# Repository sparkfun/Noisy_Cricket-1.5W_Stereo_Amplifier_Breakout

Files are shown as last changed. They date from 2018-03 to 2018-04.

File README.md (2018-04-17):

SparkFun Noisy Cricket Stereo Amplifier - 1.5W
==========================================

Noisy Cricket

[*SparkFun Noisy Cricket Stereo Amplifier - 1.5W (DEV-14475)*](https://www.sparkfun.com/products/14475)

The Noisy Cricket is a 300mW stereo amplifier which can be configured to output up to 1.5W of mono amplification.
With a dual-gang pot you can control the volume with a single pot, as well as turn power on and off!

Repository Contents
-------------------
* **/Hardware** - All Eagle design files (.brd, .sch)
* **/Production** - Test bed files and production panel files

Documentation
--------------
* **[Hookup Guide](https://learn.sparkfun.com/tutorials/noisy-cricket-stereo-amplifier---15w-hookup-guide)** - Basic hookup guide for the Noisy Cricket.

License Information
-------------------

This product is _**open source**_! 

Please review the LICENSE.md file for license information. 

If you have any questions or concerns on licensing, please contact techsupport@sparkfun.com.

Distributed as-is; no warranty is given.

- Your friends at SparkFun.

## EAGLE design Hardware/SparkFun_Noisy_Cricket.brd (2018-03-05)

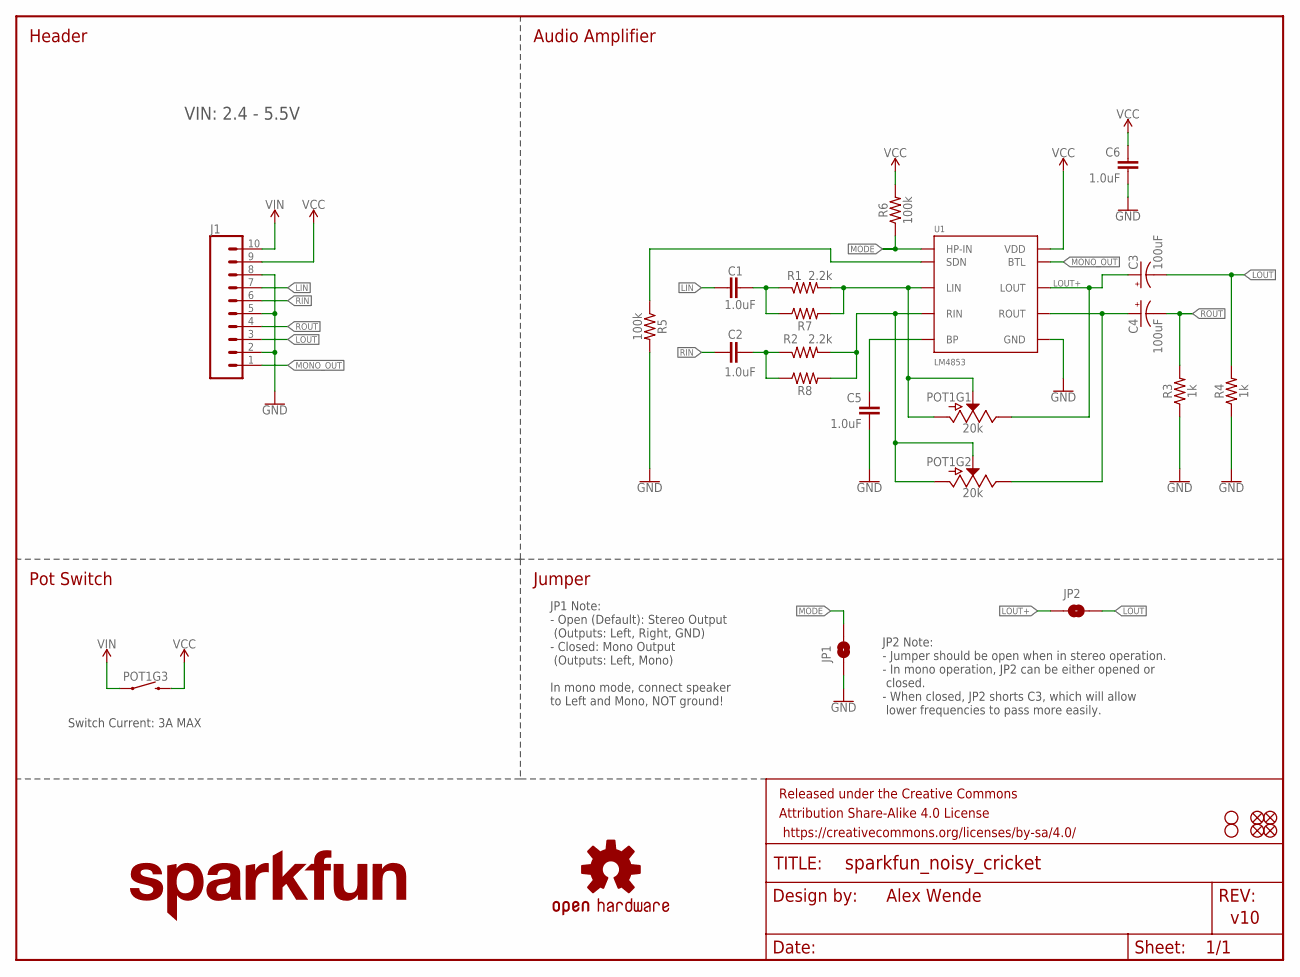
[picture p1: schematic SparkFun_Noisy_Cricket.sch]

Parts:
C1, C2, C5, C6: 1.0uF; 0603
C3, C4: 100uF; PANASONIC_D
FD1, FD2, FD3, FD4: FIDUCIALUFIDUCIAL; FIDUCIAL-MICRO
FRAME1: FRAME-LETTER; CREATIVE_COMMONS
H1, H2: STAND-OFF
J1: CONN_10NO_SILK_PTH_FEMALE; 1X10_NO_SILK
JP1, JP2: JUMPER-SMT_2_NO_NO-SILK; SMT-JUMPER_2_NO_NO-SILK
LOGO1: SFE_LOGO_NAME.1_INCH; SFE_LOGO_NAME_.1
LOGO2: OSHW-LOGOS; OSHW-LOGO-S
POT1: 20k; POT-DUAL-SWITCH-PTH
R1, R2: 2.2k; 0603
R3, R4: 1k; 0603
R5, R6: 100k; 0603
R7, R8: AXIAL-0.3-KIT
U1: LM4853; TFSOP-10

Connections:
5V: C6.1, J1.9, POT1.SW2 (2), R6.2, U1.VDD
GND: C5.2, C6.2, J1.2, J1.5, J1.8, JP1.1, R3.1, R4.1, R5.2, U1.GND
LIN: C1.1, J1.7
LOUT: C3.-, J1.3, JP2.2, R4.2
LOUT+: C3.+, JP2.1, POT1.A3 (E), U1.LOUT
MODE: JP1.2, R6.1, U1.HP-IN
MONO_OUT: J1.1, U1.BTL
unnamed: C1.2, R1.1, R7.P$1 (1)
unnamed: C5.1, U1.BP
unnamed: C2.2, R2.1, R8.P$1 (1)
unnamed: R5.1, U1.SDN
unnamed: C4.+, POT1.B3 (E), U1.ROUT
unnamed: POT1.A1 (A), POT1.A2 (S), R1.2, R7.P$2 (2), U1.LIN
unnamed: POT1.B1 (A), POT1.B2 (S), R2.2, R8.P$2 (2), U1.RIN
RIN: C2.1, J1.6
ROUT: C4.-, J1.4, R3.2
VIN: J1.10, POT1.SW1 (1)

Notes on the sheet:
JP1 Note: - Open (Default): Stereo Output (Outputs: Left, Right, GND) - Closed: Mono Output (Outputs: Left, Mono) In mono mode, connect speaker to Left and Mono, NOT ground!
Jumper
Audio Amplifier
Header
Pot Switch
Alex Wende
v10
VIN: 2.4 - 5.5V
Switch Current: 3A MAX
JP2 Note: - Jumper should be open when in stereo operation. - In mono operation, JP2 can be either opened or closed. - When closed, JP2 shorts C3, which will allow lower frequencies to pass more easily.

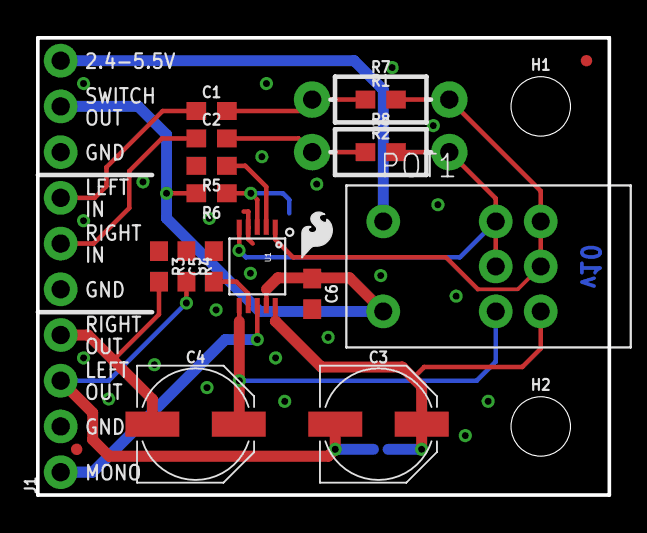
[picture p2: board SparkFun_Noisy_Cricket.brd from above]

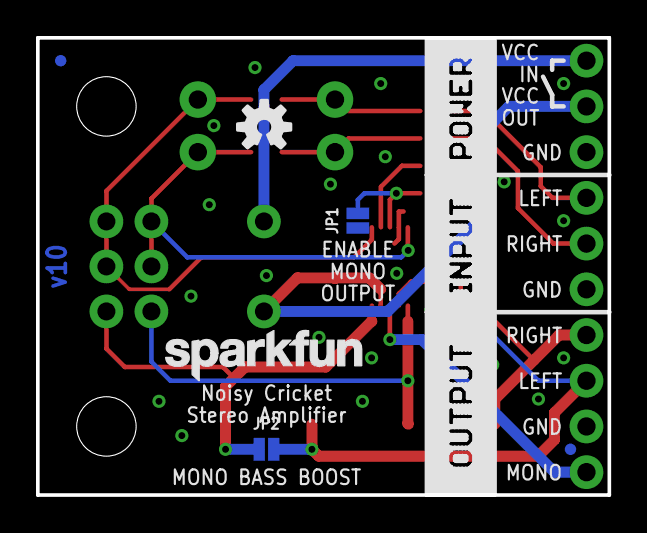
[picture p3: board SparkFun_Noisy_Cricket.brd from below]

Board: 2 copper layers, 31.8 x 25.4 mm, 29 parts (6 on the bottom side), 17 nets.

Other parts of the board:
U$1: SFE_LOGO_FLAME_.1

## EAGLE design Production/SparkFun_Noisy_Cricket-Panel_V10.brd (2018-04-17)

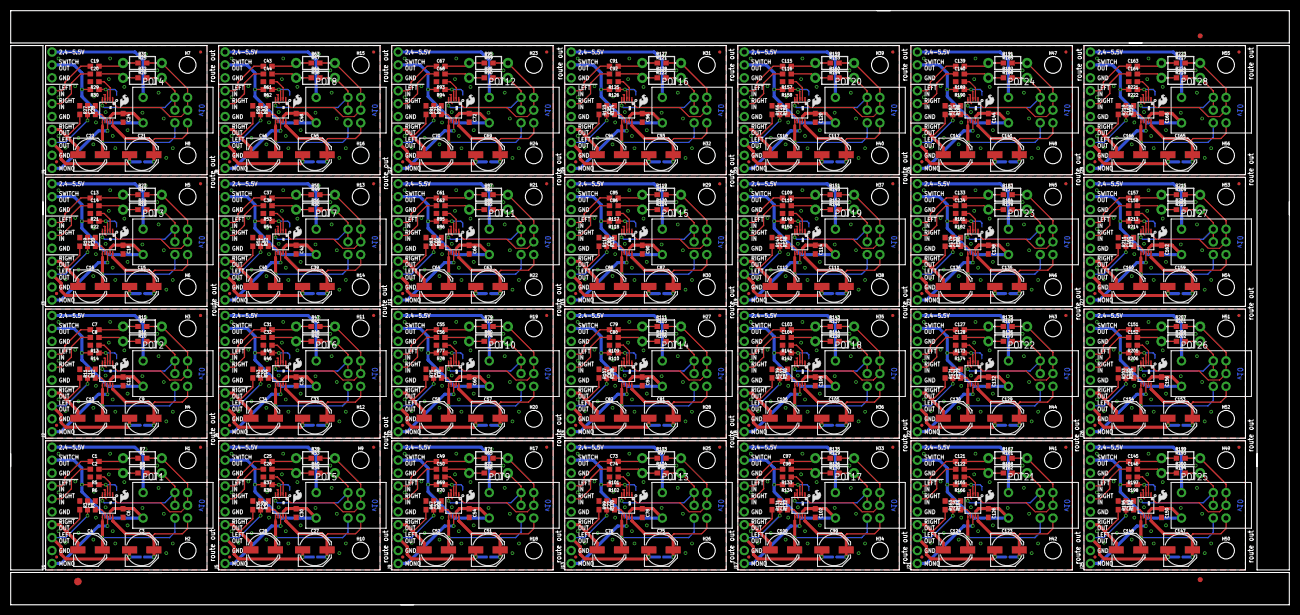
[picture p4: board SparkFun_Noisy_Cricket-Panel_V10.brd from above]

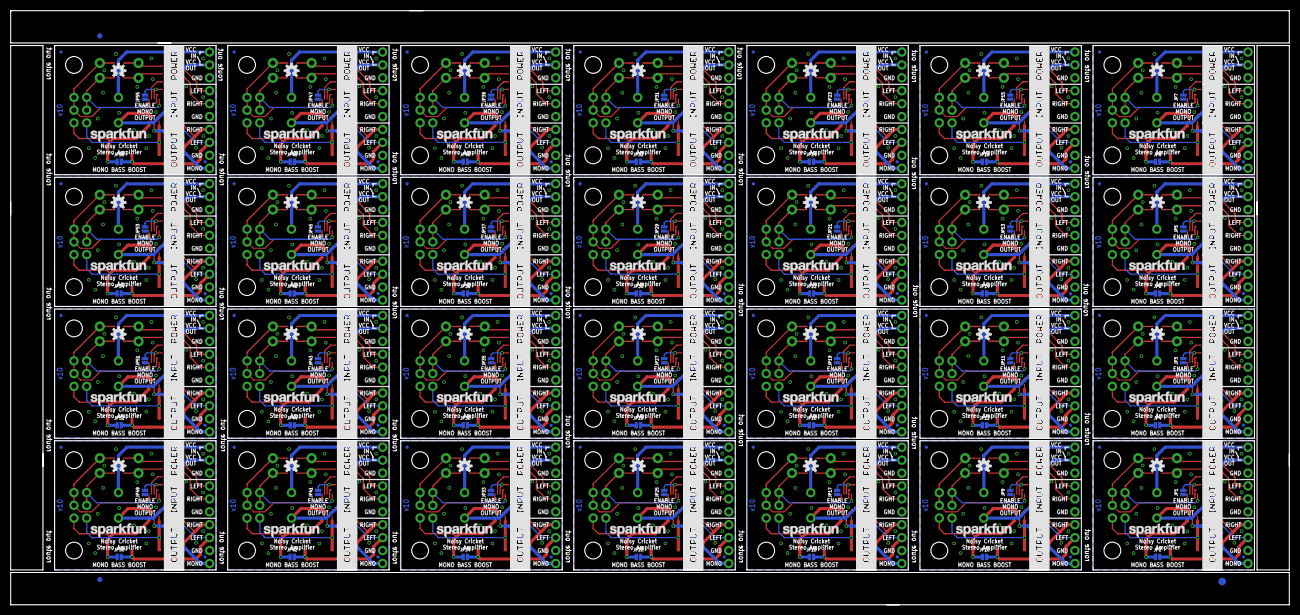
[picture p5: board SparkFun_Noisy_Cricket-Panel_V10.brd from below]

Board: 2 copper layers, 251.5 x 116.8 mm, 790 parts (171 on the bottom side), 476 nets.

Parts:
C1, C2, C5, C6, C7, C8, C11, C12, C13, C14, C17, C18, C19, C20, C23, C24, C25, C26, C29, C30, C31, C32, C35, C36, C37, C38, C41, C42, C43, C44, C47, C48, C49, C50, C53, C54, C55, C56, C59, C60, C61, C62, C65, C66, C67, C68, C71, C72, C73, C74, C77, C78, C79, C80, C83, C84, C85, C86, C89, C90, C91, C92, C95, C96, C97, C98, C101, C102, C103, C104, C107, C108, C109, C110, C113, C114, C115, C116, C119, C120, C121, C122, C125, C126, C127, C128, C131, C132, C133, C134, C137, C138, C139, C140, C143, C144, C145, C146, C149, C150, C151, C152, C155, C156, C157, C158, C161, C162, C163, C164, C167, C168: 1.0uF; 0603
C3, C4, C9, C10, C15, C16, C21, C22, C27, C28, C33, C34, C39, C40, C45, C46, C51, C52, C57, C58, C63, C64, C69, C70, C75, C76, C81, C82, C87, C88, C93, C94, C99, C100, C105, C106, C111, C112, C117, C118, C123, C124, C129, C130, C135, C136, C141, C142, C147, C148, C153, C154, C159, C160, C165, C166: 100uF; PANASONIC_D
E$1, E$2: FIDUCIAL-1.5X3
E$3, E$4, E$5, E$7: FIDUCIAL-1X2
FD1, FD2, FD3, FD4, FD5, FD6, FD7, FD8, FD9, FD10, FD11, FD12, FD13, FD14, FD15, FD16, FD17, FD18, FD19, FD20, FD21, FD22, FD23, FD24, FD25, FD26, FD27, FD28, FD29, FD30, FD31, FD32, FD33, FD34, FD35, FD36, FD37, FD38, FD39, FD40, FD41, FD42, FD43, FD44, FD45, FD46, FD47, FD48, FD49, FD50, FD51, FD52, FD53, FD54, FD55, FD56, FD57, FD58, FD59, FD60, FD61, FD62, FD63, FD64, FD65, FD66, FD67, FD68, FD69, FD70, FD71, FD72, FD73, FD74, FD75, FD76, FD77, FD78, FD79, FD80, FD81, FD82, FD83, FD84, FD85, FD86, FD87, FD88, FD89, FD90, FD91, FD92, FD93, FD94, FD95, FD96, FD97, FD98, FD99, FD100, FD101, FD102, FD103, FD104, FD105, FD106, FD107, FD108, FD109, FD110, FD111, FD112: FIDUCIALUFIDUCIAL; FIDUCIAL-MICRO
H1, H2, H3, H4, H5, H6, H7, H8, H9, H10, H11, H12, H13, H14, H15, H16, H17, H18, H19, H20, H21, H22, H23, H24, H25, H26, H27, H28, H29, H30, H31, H32, H33, H34, H35, H36, H37, H38, H39, H40, H41, H42, H43, H44, H45, H46, H47, H48, H49, H50, H51, H52, H53, H54, H55, H56: STAND-OFF
J1, J2, J3, J4, J5, J6, J7, J8, J9, J10, J11, J12, J13, J14, J15, J16, J17, J18, J19, J20, J21, J22, J23, J24, J25, J26, J27, J28: 1X10_NO_SILK
JP1, JP2, JP3, JP4, JP5, JP6, JP7, JP8, JP9, JP10, JP11, JP12, JP13, JP14, JP15, JP16, JP17, JP18, JP19, JP20, JP21, JP22, JP23, JP24, JP25, JP26, JP27, JP28, JP29, JP30, JP31, JP32, JP33, JP34, JP35, JP36, JP37, JP38, JP39, JP40, JP41, JP42, JP43, JP44, JP45, JP46, JP47, JP48, JP49, JP50, JP51, JP52, JP53, JP54, JP55, JP56: SMT-JUMPER_2_NO_NO-SILK
LOGO1, LOGO3, LOGO5, LOGO7, LOGO9, LOGO11, LOGO13, LOGO15, LOGO17, LOGO19, LOGO21, LOGO23, LOGO25, LOGO27, LOGO29, LOGO31, LOGO33, LOGO35, LOGO37, LOGO39, LOGO41, LOGO43, LOGO45, LOGO47, LOGO49, LOGO51, LOGO53, LOGO55: SFE_LOGO_NAME.1_INCH; SFE_LOGO_NAME_.1
LOGO2, LOGO4, LOGO6, LOGO8, LOGO10, LOGO12, LOGO14, LOGO16, LOGO18, LOGO20, LOGO22, LOGO24, LOGO26, LOGO28, LOGO30, LOGO32, LOGO34, LOGO36, LOGO38, LOGO40, LOGO42, LOGO44, LOGO46, LOGO48, LOGO50, LOGO52, LOGO54, LOGO56: OSHW-LOGOS; OSHW-LOGO-S
POT1, POT2, POT3, POT4, POT5, POT6, POT7, POT8, POT9, POT10, POT11, POT12, POT13, POT14, POT15, POT16, POT17, POT18, POT19, POT20, POT21, POT22, POT23, POT24, POT25, POT26, POT27, POT28: 20k; POT-DUAL-SWITCH-PTH
R1, R2, R9, R10, R17, R18, R25, R26, R33, R34, R41, R42, R49, R50, R57, R58, R65, R66, R73, R74, R81, R82, R89, R90, R97, R98, R105, R106, R113, R114, R121, R122, R129, R130, R137, R138, R145, R146, R153, R154, R161, R162, R169, R170, R177, R178, R185, R186, R193, R194, R201, R202, R209, R210, R217, R218: 2.2k; 0603
R3, R4, R11, R12, R19, R20, R27, R28, R35, R36, R43, R44, R51, R52, R59, R60, R67, R68, R75, R76, R83, R84, R91, R92, R99, R100, R107, R108, R115, R116, R123, R124, R131, R132, R139, R140, R147, R148, R155, R156, R163, R164, R171, R172, R179, R180, R187, R188, R195, R196, R203, R204, R211, R212, R219, R220: 1k; 0603
R5, R6, R13, R14, R21, R22, R29, R30, R37, R38, R45, R46, R53, R54, R61, R62, R69, R70, R77, R78, R85, R86, R93, R94, R101, R102, R109, R110, R117, R118, R125, R126, R133, R134, R141, R142, R149, R150, R157, R158, R165, R166, R173, R174, R181, R182, R189, R190, R197, R198, R205, R206, R213, R214, R221, R222: 100k; 0603
R7, R8, R15, R16, R23, R24, R31, R32, R39, R40, R47, R48, R55, R56, R63, R64, R71, R72, R79, R80, R87, R88, R95, R96, R103, R104, R111, R112, R119, R120, R127, R128, R135, R136, R143, R144, R151, R152, R159, R160, R167, R168, R175, R176, R183, R184, R191, R192, R199, R200, R207, R208, R215, R216, R223, R224: AXIAL-0.3-KIT
U1, U2, U3, U4, U5, U6, U7, U8, U9, U10, U11, U12, U13, U14, U15, U16, U17, U18, U19, U20, U21, U22, U23, U24, U25, U26, U27, U28: LM4853; TFSOP-10
U$1, U$2, U$3, U$4, U$5, U$6, U$7, U$8, U$9, U$10, U$11, U$12, U$13, U$14, U$15, U$16, U$17, U$18, U$19, U$20, U$21, U$22, U$23, U$24, U$25, U$26, U$27, U$28: SFE_LOGO_FLAME_.1

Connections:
5V: C6.1, J1.9, POT1.SW2, R6.2, U1.VDD
5V1: C12.1, J2.9, POT2.SW2, R14.2, U2.VDD
5V2: C18.1, J3.9, POT3.SW2, R22.2, U3.VDD
5V3: C24.1, J4.9, POT4.SW2, R30.2, U4.VDD
5V4: C30.1, J5.9, POT5.SW2, R38.2, U5.VDD
5V5: C36.1, J6.9, POT6.SW2, R46.2, U6.VDD
5V6: C42.1, J7.9, POT7.SW2, R54.2, U7.VDD
5V7: C48.1, J8.9, POT8.SW2, R62.2, U8.VDD
5V8: C54.1, J9.9, POT9.SW2, R70.2, U9.VDD
5V9: C60.1, J10.9, POT10.SW2, R78.2, U10.VDD
5V10: C66.1, J11.9, POT11.SW2, R86.2, U11.VDD
5V11: C72.1, J12.9, POT12.SW2, R94.2, U12.VDD
5V12: C78.1, J13.9, POT13.SW2, R102.2, U13.VDD
5V13: C84.1, J14.9, POT14.SW2, R110.2, U14.VDD
5V14: C90.1, J15.9, POT15.SW2, R118.2, U15.VDD
5V15: C96.1, J16.9, POT16.SW2, R126.2, U16.VDD
5V16: C102.1, J17.9, POT17.SW2, R134.2, U17.VDD
5V17: C108.1, J18.9, POT18.SW2, R142.2, U18.VDD
5V18: C114.1, J19.9, POT19.SW2, R150.2, U19.VDD
5V19: C120.1, J20.9, POT20.SW2, R158.2, U20.VDD
5V20: C126.1, J21.9, POT21.SW2, R166.2, U21.VDD
5V21: C132.1, J22.9, POT22.SW2, R174.2, U22.VDD
5V22: C138.1, J23.9, POT23.SW2, R182.2, U23.VDD
5V23: C144.1, J24.9, POT24.SW2, R190.2, U24.VDD
5V24: C150.1, J25.9, POT25.SW2, R198.2, U25.VDD
5V25: C156.1, J26.9, POT26.SW2, R206.2, U26.VDD
5V26: C162.1, J27.9, POT27.SW2, R214.2, U27.VDD
5V27: C168.1, J28.9, POT28.SW2, R222.2, U28.VDD
GND: C5.2, C6.2, J1.2, J1.5, J1.8, JP1.1, R3.1, R4.1, R5.2, U1.GND
GND1: C11.2, C12.2, J2.2, J2.5, J2.8, JP3.1, R11.1, R12.1, R13.2, U2.GND
GND2: C17.2, C18.2, J3.2, J3.5, J3.8, JP5.1, R19.1, R20.1, R21.2, U3.GND
GND3: C23.2, C24.2, J4.2, J4.5, J4.8, JP7.1, R27.1, R28.1, R29.2, U4.GND
GND4: C29.2, C30.2, J5.2, J5.5, J5.8, JP9.1, R35.1, R36.1, R37.2, U5.GND
GND5: C35.2, C36.2, J6.2, J6.5, J6.8, JP11.1, R43.1, R44.1, R45.2, U6.GND
GND6: C41.2, C42.2, J7.2, J7.5, J7.8, JP13.1, R51.1, R52.1, R53.2, U7.GND
GND7: C47.2, C48.2, J8.2, J8.5, J8.8, JP15.1, R59.1, R60.1, R61.2, U8.GND
GND8: C53.2, C54.2, J9.2, J9.5, J9.8, JP17.1, R67.1, R68.1, R69.2, U9.GND
GND9: C59.2, C60.2, J10.2, J10.5, J10.8, JP19.1, R75.1, R76.1, R77.2, U10.GND
GND10: C65.2, C66.2, J11.2, J11.5, J11.8, JP21.1, R83.1, R84.1, R85.2, U11.GND
GND11: C71.2, C72.2, J12.2, J12.5, J12.8, JP23.1, R91.1, R92.1, R93.2, U12.GND
GND12: C77.2, C78.2, J13.2, J13.5, J13.8, JP25.1, R99.1, R100.1, R101.2, U13.GND
GND13: C83.2, C84.2, J14.2, J14.5, J14.8, JP27.1, R107.1, R108.1, R109.2, U14.GND
GND14: C89.2, C90.2, J15.2, J15.5, J15.8, JP29.1, R115.1, R116.1, R117.2, U15.GND
GND15: C95.2, C96.2, J16.2, J16.5, J16.8, JP31.1, R123.1, R124.1, R125.2, U16.GND
GND16: C101.2, C102.2, J17.2, J17.5, J17.8, JP33.1, R131.1, R132.1, R133.2, U17.GND
GND17: C107.2, C108.2, J18.2, J18.5, J18.8, JP35.1, R139.1, R140.1, R141.2, U18.GND
GND18: C113.2, C114.2, J19.2, J19.5, J19.8, JP37.1, R147.1, R148.1, R149.2, U19.GND
GND19: C119.2, C120.2, J20.2, J20.5, J20.8, JP39.1, R155.1, R156.1, R157.2, U20.GND
GND20: C125.2, C126.2, J21.2, J21.5, J21.8, JP41.1, R163.1, R164.1, R165.2, U21.GND
GND21: C131.2, C132.2, J22.2, J22.5, J22.8, JP43.1, R171.1, R172.1, R173.2, U22.GND
GND22: C137.2, C138.2, J23.2, J23.5, J23.8, JP45.1, R179.1, R180.1, R181.2, U23.GND
GND23: C143.2, C144.2, J24.2, J24.5, J24.8, JP47.1, R187.1, R188.1, R189.2, U24.GND
GND24: C149.2, C150.2, J25.2, J25.5, J25.8, JP49.1, R195.1, R196.1, R197.2, U25.GND
GND25: C155.2, C156.2, J26.2, J26.5, J26.8, JP51.1, R203.1, R204.1, R205.2, U26.GND
GND26: C161.2, C162.2, J27.2, J27.5, J27.8, JP53.1, R211.1, R212.1, R213.2, U27.GND
GND27: C167.2, C168.2, J28.2, J28.5, J28.8, JP55.1, R219.1, R220.1, R221.2, U28.GND
LIN: C1.1, J1.7
LIN1: C7.1, J2.7
LIN2: C13.1, J3.7
LIN3: C19.1, J4.7
LIN4: C25.1, J5.7
LIN5: C31.1, J6.7
LIN6: C37.1, J7.7
LIN7: C43.1, J8.7
LIN8: C49.1, J9.7
LIN9: C55.1, J10.7
LIN10: C61.1, J11.7
LIN11: C67.1, J12.7
LIN12: C73.1, J13.7
LIN13: C79.1, J14.7
LIN14: C85.1, J15.7
LIN15: C91.1, J16.7
LIN16: C97.1, J17.7
LIN17: C103.1, J18.7
LIN18: C109.1, J19.7
LIN19: C115.1, J20.7
LIN20: C121.1, J21.7
LIN21: C127.1, J22.7
LIN22: C133.1, J23.7
LIN23: C139.1, J24.7
LIN24: C145.1, J25.7
LIN25: C151.1, J26.7
LIN26: C157.1, J27.7
LIN27: C163.1, J28.7
LOUT: C3.-, J1.3, JP2.2, R4.2
LOUT1: C9.-, J2.3, JP4.2, R12.2
LOUT2: C15.-, J3.3, JP6.2, R20.2
LOUT3: C21.-, J4.3, JP8.2, R28.2
LOUT4: C27.-, J5.3, JP10.2, R36.2
LOUT5: C33.-, J6.3, JP12.2, R44.2
LOUT6: C39.-, J7.3, JP14.2, R52.2
LOUT7: C45.-, J8.3, JP16.2, R60.2
LOUT8: C51.-, J9.3, JP18.2, R68.2
LOUT9: C57.-, J10.3, JP20.2, R76.2
LOUT10: C63.-, J11.3, JP22.2, R84.2
LOUT11: C69.-, J12.3, JP24.2, R92.2
LOUT12: C75.-, J13.3, JP26.2, R100.2
LOUT13: C81.-, J14.3, JP28.2, R108.2
LOUT14: C87.-, J15.3, JP30.2, R116.2
LOUT15: C93.-, J16.3, JP32.2, R124.2
LOUT16: C99.-, J17.3, JP34.2, R132.2
LOUT17: C105.-, J18.3, JP36.2, R140.2
LOUT18: C111.-, J19.3, JP38.2, R148.2
LOUT19: C117.-, J20.3, JP40.2, R156.2
LOUT20: C123.-, J21.3, JP42.2, R164.2
LOUT21: C129.-, J22.3, JP44.2, R172.2
LOUT22: C135.-, J23.3, JP46.2, R180.2
LOUT23: C141.-, J24.3, JP48.2, R188.2
LOUT24: C147.-, J25.3, JP50.2, R196.2
LOUT25: C153.-, J26.3, JP52.2, R204.2
LOUT26: C159.-, J27.3, JP54.2, R212.2
LOUT27: C165.-, J28.3, JP56.2, R220.2
LOUT+: C3.+, JP2.1, POT1.A3, U1.LOUT
LOUT+1: C9.+, JP4.1, POT2.A3, U2.LOUT
LOUT+2: C15.+, JP6.1, POT3.A3, U3.LOUT
LOUT+3: C21.+, JP8.1, POT4.A3, U4.LOUT
LOUT+4: C27.+, JP10.1, POT5.A3, U5.LOUT
LOUT+5: C33.+, JP12.1, POT6.A3, U6.LOUT
LOUT+6: C39.+, JP14.1, POT7.A3, U7.LOUT
LOUT+7: C45.+, JP16.1, POT8.A3, U8.LOUT
LOUT+8: C51.+, JP18.1, POT9.A3, U9.LOUT
LOUT+9: C57.+, JP20.1, POT10.A3, U10.LOUT
LOUT+10: C63.+, JP22.1, POT11.A3, U11.LOUT
LOUT+11: C69.+, JP24.1, POT12.A3, U12.LOUT
LOUT+12: C75.+, JP26.1, POT13.A3, U13.LOUT
LOUT+13: C81.+, JP28.1, POT14.A3, U14.LOUT
LOUT+14: C87.+, JP30.1, POT15.A3, U15.LOUT
LOUT+15: C93.+, JP32.1, POT16.A3, U16.LOUT
LOUT+16: C99.+, JP34.1, POT17.A3, U17.LOUT
LOUT+17: C105.+, JP36.1, POT18.A3, U18.LOUT
LOUT+18: C111.+, JP38.1, POT19.A3, U19.LOUT
LOUT+19: C117.+, JP40.1, POT20.A3, U20.LOUT
LOUT+20: C123.+, JP42.1, POT21.A3, U21.LOUT
LOUT+21: C129.+, JP44.1, POT22.A3, U22.LOUT
LOUT+22: C135.+, JP46.1, POT23.A3, U23.LOUT
LOUT+23: C141.+, JP48.1, POT24.A3, U24.LOUT
LOUT+24: C147.+, JP50.1, POT25.A3, U25.LOUT
LOUT+25: C153.+, JP52.1, POT26.A3, U26.LOUT
LOUT+26: C159.+, JP54.1, POT27.A3, U27.LOUT
LOUT+27: C165.+, JP56.1, POT28.A3, U28.LOUT
MODE: JP1.2, R6.1, U1.HP-IN
MODE1: JP3.2, R14.1, U2.HP-IN
MODE2: JP5.2, R22.1, U3.HP-IN
MODE3: JP7.2, R30.1, U4.HP-IN
MODE4: JP9.2, R38.1, U5.HP-IN
MODE5: JP11.2, R46.1, U6.HP-IN
MODE6: JP13.2, R54.1, U7.HP-IN
MODE7: JP15.2, R62.1, U8.HP-IN
MODE8: JP17.2, R70.1, U9.HP-IN
MODE9: JP19.2, R78.1, U10.HP-IN
MODE10: JP21.2, R86.1, U11.HP-IN
MODE11: JP23.2, R94.1, U12.HP-IN
MODE12: JP25.2, R102.1, U13.HP-IN
MODE13: JP27.2, R110.1, U14.HP-IN
MODE14: JP29.2, R118.1, U15.HP-IN
MODE15: JP31.2, R126.1, U16.HP-IN
MODE16: JP33.2, R134.1, U17.HP-IN
MODE17: JP35.2, R142.1, U18.HP-IN
MODE18: JP37.2, R150.1, U19.HP-IN
MODE19: JP39.2, R158.1, U20.HP-IN
MODE20: JP41.2, R166.1, U21.HP-IN
MODE21: JP43.2, R174.1, U22.HP-IN
MODE22: JP45.2, R182.1, U23.HP-IN
MODE23: JP47.2, R190.1, U24.HP-IN
MODE24: JP49.2, R198.1, U25.HP-IN
MODE25: JP51.2, R206.1, U26.HP-IN
MODE26: JP53.2, R214.1, U27.HP-IN
MODE27: JP55.2, R222.1, U28.HP-IN
MONO_OUT: J1.1, U1.BTL
MONO_OUT1: J2.1, U2.BTL
MONO_OUT2: J3.1, U3.BTL
MONO_OUT3: J4.1, U4.BTL
MONO_OUT4: J5.1, U5.BTL
MONO_OUT5: J6.1, U6.BTL
MONO_OUT6: J7.1, U7.BTL
MONO_OUT7: J8.1, U8.BTL
MONO_OUT8: J9.1, U9.BTL
MONO_OUT9: J10.1, U10.BTL
MONO_OUT10: J11.1, U11.BTL
MONO_OUT11: J12.1, U12.BTL
MONO_OUT12: J13.1, U13.BTL
MONO_OUT13: J14.1, U14.BTL
MONO_OUT14: J15.1, U15.BTL
MONO_OUT15: J16.1, U16.BTL
MONO_OUT16: J17.1, U17.BTL
MONO_OUT17: J18.1, U18.BTL
MONO_OUT18: J19.1, U19.BTL
MONO_OUT19: J20.1, U20.BTL
MONO_OUT20: J21.1, U21.BTL
MONO_OUT21: J22.1, U22.BTL
MONO_OUT22: J23.1, U23.BTL
MONO_OUT23: J24.1, U24.BTL
MONO_OUT24: J25.1, U25.BTL
MONO_OUT25: J26.1, U26.BTL
MONO_OUT26: J27.1, U27.BTL
MONO_OUT27: J28.1, U28.BTL
unnamed: C7.2, R9.1, R15.P$1
unnamed: R13.1, U2.SDN
unnamed: C1.2, R1.1, R7.P$1
unnamed: C11.1, U2.BP
unnamed: C5.1, U1.BP
unnamed: C2.2, R2.1, R8.P$1
unnamed: C10.+, POT2.B3, U2.ROUT
unnamed: POT2.A1, POT2.A2, R9.2, R15.P$2, U2.LIN
unnamed: R5.1, U1.SDN
unnamed: POT2.B1, POT2.B2, R10.2, R16.P$2, U2.RIN
unnamed: C8.2, R10.1, R16.P$1
unnamed: C4.+, POT1.B3, U1.ROUT
unnamed: C13.2, R17.1, R23.P$1
unnamed: R21.1, U3.SDN
unnamed: C17.1, U3.BP
unnamed: C16.+, POT3.B3, U3.ROUT
unnamed: POT3.A1, POT3.A2, R17.2, R23.P$2, U3.LIN
unnamed: POT3.B1, POT3.B2, R18.2, R24.P$2, U3.RIN
unnamed: C14.2, R18.1, R24.P$1
unnamed: C19.2, R25.1, R31.P$1
unnamed: POT1.A1, POT1.A2, R1.2, R7.P$2, U1.LIN
unnamed: R29.1, U4.SDN
unnamed: C23.1, U4.BP
unnamed: POT1.B1, POT1.B2, R2.2, R8.P$2, U1.RIN
unnamed: C22.+, POT4.B3, U4.ROUT
unnamed: POT4.A1, POT4.A2, R25.2, R31.P$2, U4.LIN
unnamed: POT4.B1, POT4.B2, R26.2, R32.P$2, U4.RIN
unnamed: C20.2, R26.1, R32.P$1
unnamed: C25.2, R33.1, R39.P$1
unnamed: R37.1, U5.SDN
unnamed: C29.1, U5.BP
unnamed: C28.+, POT5.B3, U5.ROUT
unnamed: POT5.A1, POT5.A2, R33.2, R39.P$2, U5.LIN
unnamed: POT5.B1, POT5.B2, R34.2, R40.P$2, U5.RIN
unnamed: C26.2, R34.1, R40.P$1
unnamed: C31.2, R41.1, R47.P$1
unnamed: R45.1, U6.SDN
unnamed: C35.1, U6.BP
unnamed: C34.+, POT6.B3, U6.ROUT
unnamed: POT6.A1, POT6.A2, R41.2, R47.P$2, U6.LIN
unnamed: POT6.B1, POT6.B2, R42.2, R48.P$2, U6.RIN
unnamed: C32.2, R42.1, R48.P$1
unnamed: C37.2, R49.1, R55.P$1
unnamed: R53.1, U7.SDN
unnamed: C41.1, U7.BP
unnamed: C40.+, POT7.B3, U7.ROUT
unnamed: POT7.A1, POT7.A2, R49.2, R55.P$2, U7.LIN
unnamed: POT7.B1, POT7.B2, R50.2, R56.P$2, U7.RIN
unnamed: C38.2, R50.1, R56.P$1
unnamed: C43.2, R57.1, R63.P$1
unnamed: R61.1, U8.SDN
unnamed: C47.1, U8.BP
unnamed: C46.+, POT8.B3, U8.ROUT
unnamed: POT8.A1, POT8.A2, R57.2, R63.P$2, U8.LIN
unnamed: POT8.B1, POT8.B2, R58.2, R64.P$2, U8.RIN
unnamed: C44.2, R58.1, R64.P$1
unnamed: C49.2, R65.1, R71.P$1
unnamed: R69.1, U9.SDN
unnamed: C53.1, U9.BP
unnamed: C52.+, POT9.B3, U9.ROUT
unnamed: POT9.A1, POT9.A2, R65.2, R71.P$2, U9.LIN
unnamed: POT9.B1, POT9.B2, R66.2, R72.P$2, U9.RIN
unnamed: C50.2, R66.1, R72.P$1
unnamed: C55.2, R73.1, R79.P$1
unnamed: R77.1, U10.SDN
unnamed: C59.1, U10.BP
unnamed: C58.+, POT10.B3, U10.ROUT
unnamed: POT10.A1, POT10.A2, R73.2, R79.P$2, U10.LIN
unnamed: POT10.B1, POT10.B2, R74.2, R80.P$2, U10.RIN
unnamed: C56.2, R74.1, R80.P$1
unnamed: C61.2, R81.1, R87.P$1
unnamed: R85.1, U11.SDN
unnamed: C65.1, U11.BP
unnamed: C64.+, POT11.B3, U11.ROUT
unnamed: POT11.A1, POT11.A2, R81.2, R87.P$2, U11.LIN
unnamed: POT11.B1, POT11.B2, R82.2, R88.P$2, U11.RIN
unnamed: C62.2, R82.1, R88.P$1
unnamed: C67.2, R89.1, R95.P$1
unnamed: R93.1, U12.SDN
unnamed: C71.1, U12.BP
unnamed: C70.+, POT12.B3, U12.ROUT
unnamed: POT12.A1, POT12.A2, R89.2, R95.P$2, U12.LIN
unnamed: POT12.B1, POT12.B2, R90.2, R96.P$2, U12.RIN
unnamed: C68.2, R90.1, R96.P$1
unnamed: C73.2, R97.1, R103.P$1
unnamed: R101.1, U13.SDN
unnamed: C77.1, U13.BP
unnamed: C76.+, POT13.B3, U13.ROUT
unnamed: POT13.A1, POT13.A2, R97.2, R103.P$2, U13.LIN
unnamed: POT13.B1, POT13.B2, R98.2, R104.P$2, U13.RIN
unnamed: C74.2, R98.1, R104.P$1
unnamed: C79.2, R105.1, R111.P$1
unnamed: R109.1, U14.SDN
unnamed: C83.1, U14.BP
unnamed: C82.+, POT14.B3, U14.ROUT
unnamed: POT14.A1, POT14.A2, R105.2, R111.P$2, U14.LIN
unnamed: POT14.B1, POT14.B2, R106.2, R112.P$2, U14.RIN
unnamed: C80.2, R106.1, R112.P$1
unnamed: C85.2, R113.1, R119.P$1
unnamed: R117.1, U15.SDN
unnamed: C89.1, U15.BP
unnamed: C88.+, POT15.B3, U15.ROUT
unnamed: POT15.A1, POT15.A2, R113.2, R119.P$2, U15.LIN
unnamed: POT15.B1, POT15.B2, R114.2, R120.P$2, U15.RIN
unnamed: C86.2, R114.1, R120.P$1
unnamed: C91.2, R121.1, R127.P$1
unnamed: R125.1, U16.SDN
unnamed: C95.1, U16.BP
unnamed: C94.+, POT16.B3, U16.ROUT
unnamed: POT16.A1, POT16.A2, R121.2, R127.P$2, U16.LIN
unnamed: POT16.B1, POT16.B2, R122.2, R128.P$2, U16.RIN
unnamed: C92.2, R122.1, R128.P$1
unnamed: C97.2, R129.1, R135.P$1
unnamed: R133.1, U17.SDN
unnamed: C101.1, U17.BP
unnamed: C100.+, POT17.B3, U17.ROUT
unnamed: POT17.A1, POT17.A2, R129.2, R135.P$2, U17.LIN
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

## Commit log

2017-09-05 Initial Commit
    Added Eagles files for proto version 01
    [SparkFun_Pocket_Amp.brd, SparkFun_Pocket_Amp.sch]
2017-09-26 Added PROD_ID to C12
    [SparkFun_Pocket_Amp.brd, SparkFun_Pocket_Amp.sch]
2017-09-26 DFM Changes
    Added values missing on a few parts
    [SparkFun_Pocket_Amp.brd, SparkFun_Pocket_Amp.sch]
2018-01-31 Updated board from Pocket Amp to Noisy Cricket
    [SparkFun_Noisy_Cricket.brd, SparkFun_Noisy_Cricket.sch, SparkFun_Pocket_Amp.brd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]
2018-02-02 Design Review Changes
    - Moved JP1 further away from POT1
    - Added JP2 to short C3 and increase bass frequency reponse in mono
    operation
    [SparkFun_Noisy_Cricket.brd, SparkFun_Noisy_Cricket.sch]
2018-02-02 Corrected board position
    - Board was saved upside down, corrected by flipping board back around
    and resaving.
    [SparkFun_Noisy_Cricket.brd]
2018-02-27 v10 Changes
    - Replaced C1/C2 with X7R capacitors with a better low end frequency
    response.
    - Moved C3/C4 further away from POT1.
    - Replaced R1/R2 with 2.2k resistors instead of 20k.
    - Added lines to top silk to separate Power/Input/Output sections.
    - Changed "Mono Enable" silk on bottom layer to "Mono Output".
    [SparkFun_Noisy_Cricket.brd, SparkFun_Noisy_Cricket.sch]
2018-02-27 v10 Changes cont.
    - New 1.0uF capacitors weren't added to previous commit. Added correct
    capacitors.
    [SparkFun_Noisy_Cricket.brd, SparkFun_Noisy_Cricket.sch]
2018-02-27 Design Review Changes
    minor changes to silk after design review
    [SparkFun_Noisy_Cricket.brd, SparkFun_Noisy_Cricket.sch]
2018-03-05 QC Fixes
    - Increased anular ring of pot from AUTO to 0.074".
    - Fixed schematic version number to 10.
    [SparkFun_Noisy_Cricket.brd, SparkFun_Noisy_Cricket.sch]
2018-03-09 V10 panel
    [SparkFun_Noisy_Cricket-Panel_V10.brd]
2018-03-09 moved to origin
    [SparkFun_Noisy_Cricket-Panel_V10.brd]

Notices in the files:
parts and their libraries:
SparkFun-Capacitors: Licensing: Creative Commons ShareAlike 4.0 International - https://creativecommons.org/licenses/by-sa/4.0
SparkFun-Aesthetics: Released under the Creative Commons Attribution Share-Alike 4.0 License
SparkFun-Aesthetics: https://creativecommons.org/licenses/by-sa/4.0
